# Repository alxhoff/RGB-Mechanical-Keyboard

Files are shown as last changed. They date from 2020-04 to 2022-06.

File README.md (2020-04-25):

# RGB-Mechanical-Keyboard

In this repository you will find my PCBs for a mechanical keyboard based around cherry switches and WS2812 single-wire serial RGB LEDs.
The keyboard is broken into two parts, the main keyboard PCB that houses the LEDS, power supply and switches, and a daughterboard that connects via ribbon cable where the controlling microcontroller is mounter.

The keyboard PCB in the latest generation has been been built such that the bottom row can be arranged in many different ways, allowing for unique configuration.
On the to-do list is to add this sort of customizability to more of the keyboard, eg. replacing capslock (totally useless) with a couple of macro keys.

# TODO for V2.1

- [x] Make second-from-bottom row more customizable
- [x] Add a usb 2.0 hub and a couple of usb-c ports to the keyboard.
- [X] Add jumpers to configure rgb rows, for example, daisy chaining multiple rows to reduce required pin count
- [ ] STM32F411 "Blackpill" control board
- [X] Add port for connecting a joystick for mouse functionality
- [X] Add switch for toggling 'BOOT' protocol, ie. device can recognize that it should send 8 byte BOOT compatible HID reports
- [X] Update existing control boards to handle 30 pin ribbon cable
- [X] Add hotswappable sockets
- [X] Make mounting holes elongated to allow for less precision during case fabrication

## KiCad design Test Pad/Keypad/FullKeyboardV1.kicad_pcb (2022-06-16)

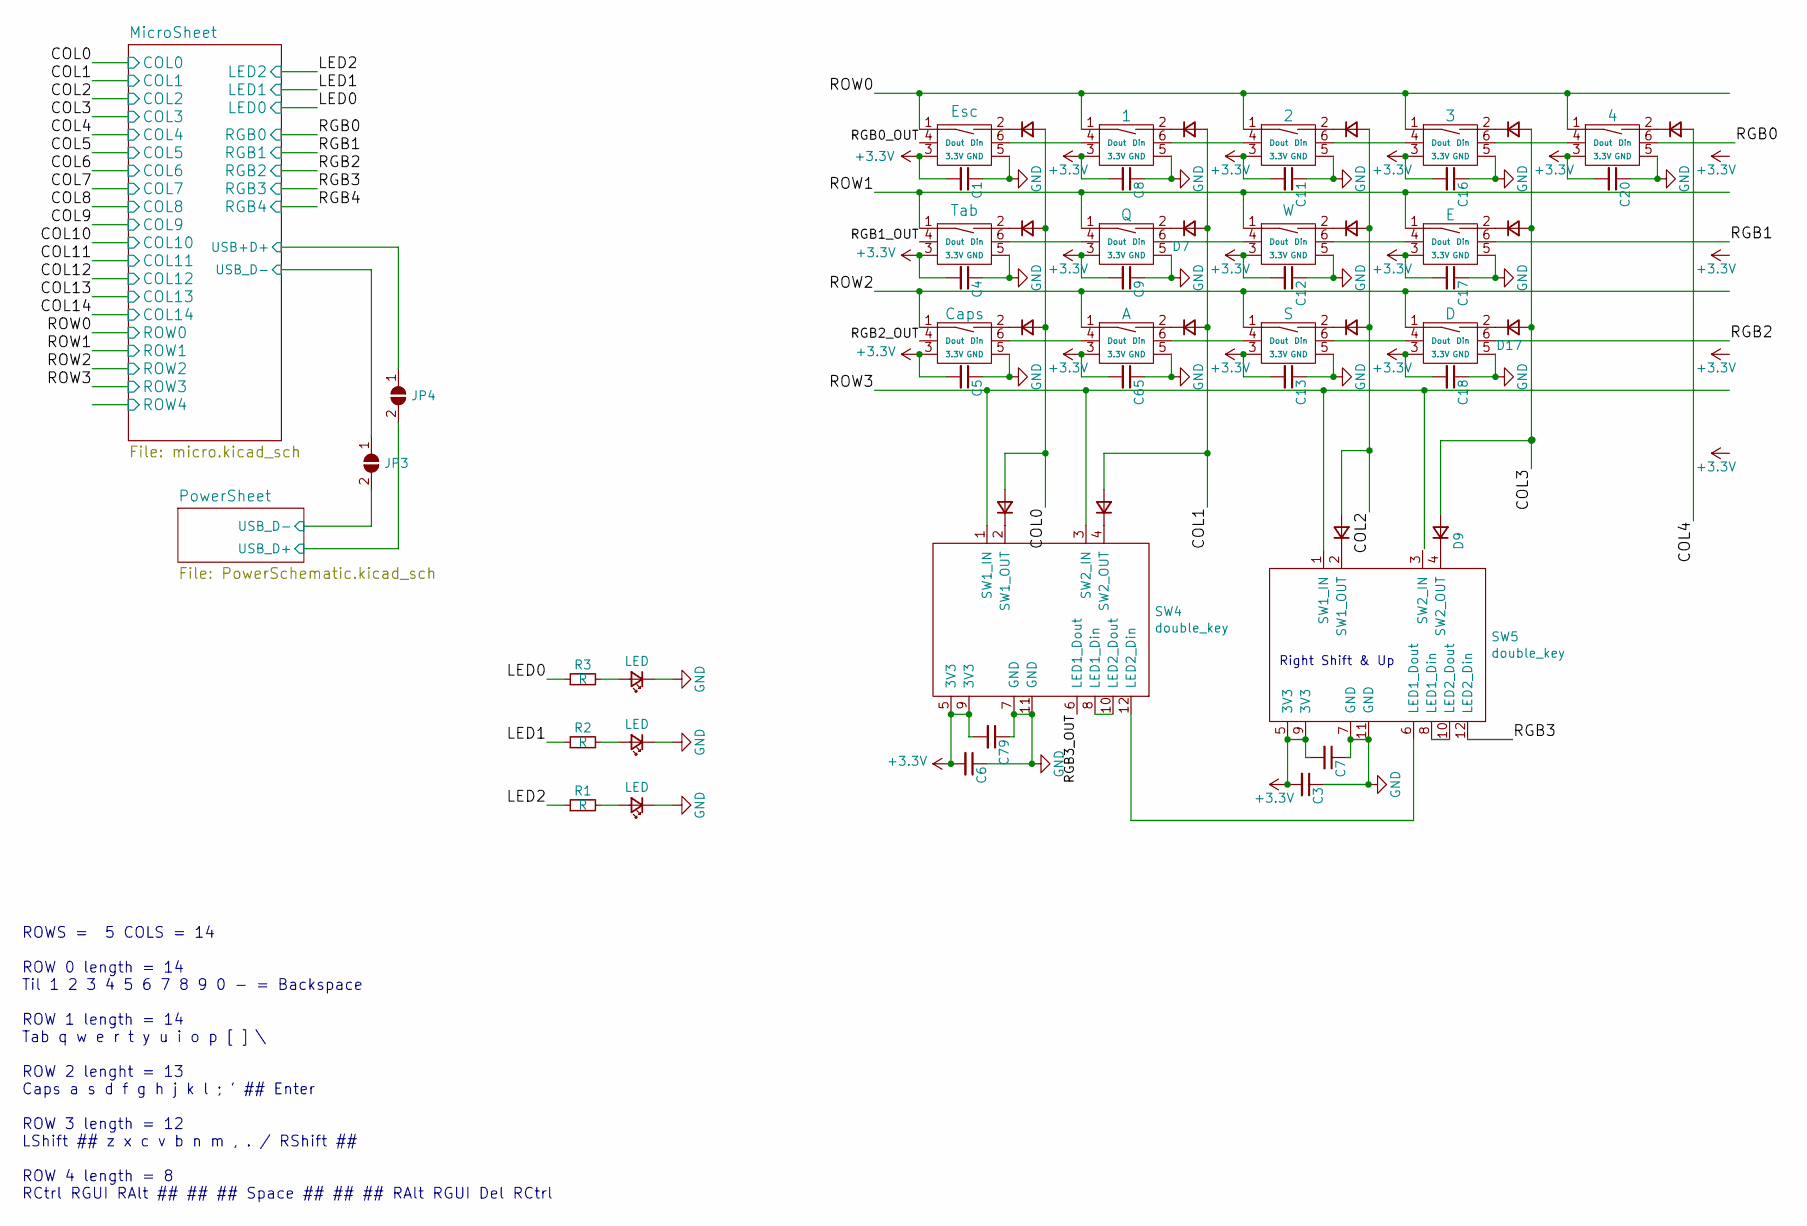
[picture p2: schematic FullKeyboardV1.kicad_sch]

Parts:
C1, C3, C4, C5, C6, C7, C8, C9, C11, C12, C13, C16, C17, C18, C20, C65, C79: C_Small; C_0603_1608Metric
D1, D2, D3, D4, D5, D6, D7, D8, D9, D10, D11, D12, D15, D16, D17, D19, D77: D_Small; D_SOD-123
D70, D71, D72: LED; LED_0603_1608Metric
JP3, JP4: SolderJumper_2_Open; SolderJumper-2_P1.3mm_Open_RoundedPad1.0x1.5mm
R1, R2, R3: R; R_0603_1608Metric
SW1: Esc; RGB_CHERRY_PCB_100H_HOTSWAP
SW2: Tab; RGB_CHERRY_PCB_150H_HOTSWAP
SW3: Caps; RGB_CHERRY_PCB_175H_HOTSWAP
SW4: double_key; RGB_CHERRY_SHIFT_ROW_LEFT
SW5: double_key; RGB_CHERRY_SHIFT_RIGHT_2.0
SW6: 1; RGB_CHERRY_PCB_100H_HOTSWAP
SW7: Q; RGB_CHERRY_PCB_100H_HOTSWAP
SW8: A; RGB_CHERRY_PCB_100H_HOTSWAP
SW10: 2; RGB_CHERRY_PCB_100H_HOTSWAP
SW11: W; RGB_CHERRY_PCB_100H_HOTSWAP
SW12: S; RGB_CHERRY_PCB_100H_HOTSWAP
SW15: 3; RGB_CHERRY_PCB_100H_HOTSWAP
SW16: E; RGB_CHERRY_PCB_100H_HOTSWAP
SW17: D; RGB_CHERRY_PCB_100H_HOTSWAP
SW19: 4; RGB_CHERRY_PCB_100H_HOTSWAP

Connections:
/COL0: D1.2 (A), D2.2 (A), D3.2 (A), D4.2 (A); also elsewhere on the board
/COL1: D6.2 (A), D7.2 (A), D8.2 (A), D77.2 (A); also elsewhere on the board
/COL2: D5.2 (A), D10.2 (A), D11.2 (A), D12.2 (A); also elsewhere on the board
/COL3: D9.2 (A), D15.2 (A), D16.2 (A), D17.2 (A); also elsewhere on the board
/COL4: D19.2 (A); also elsewhere on the board
/LED0: R3.1; also elsewhere on the board
/LED1: R2.1; also elsewhere on the board
/LED2: R1.1; also elsewhere on the board
/MicroSheet/USB+D+: JP4.1 (A); also elsewhere on the board
/MicroSheet/USB_D-: JP3.1 (A); also elsewhere on the board
/PowerSheet/USB_D+: JP4.2 (B); also elsewhere on the board
/PowerSheet/USB_D-: JP3.2 (B); also elsewhere on the board
/RGB0: SW19.6 (Din); also elsewhere on the board
/RGB0_OUT: SW1.4 (Dout)
/RGB1: SW16.6 (Din); also elsewhere on the board
/RGB1_OUT: SW2.4 (Dout)
/RGB2: SW17.6 (Din); also elsewhere on the board
/RGB2_OUT: SW3.4 (Dout)
/RGB3: SW5.12 (LED2_Din); also elsewhere on the board
/RGB3_OUT: SW4.6 (LED1_Dout)
/ROW0: SW1.1, SW6.1, SW10.1, SW15.1, SW19.1; also elsewhere on the board
/ROW1: SW2.1, SW7.1, SW11.1, SW16.1; also elsewhere on the board
/ROW2: SW3.1, SW8.1, SW12.1, SW17.1; also elsewhere on the board
/ROW3: SW4.1 (SW1_IN), SW4.3 (SW2_IN), SW5.1 (SW1_IN); also elsewhere on the board
GND: C1.1, C3.1, C4.1, C5.1, C6.1, C7.1, C8.1, C9.1, C11.1, C12.1, C13.1, C16.1, C17.1, C18.1, C20.1, C65.1, C79.1, D70.1 (K), D71.1 (K), D72.1 (K), SW1.5 (GND), SW2.5 (GND), SW3.5 (GND), SW4.7 (GND), SW4.11 (GND), SW5.7 (GND), SW5.11 (GND), SW6.5 (GND), SW7.5 (GND), SW8.5 (GND), SW10.5 (GND), SW11.5 (GND), SW12.5 (GND), SW15.5 (GND), SW16.5 (GND), SW17.5 (GND), SW19.5 (GND); also elsewhere on the board
unnamed: D1.1 (K), SW1.2
unnamed: D2.1 (K), SW2.2
unnamed: D3.1 (K), SW3.2
unnamed: D4.1 (K), SW4.2 (SW1_OUT)
unnamed: D5.1 (K), SW5.2 (SW1_OUT)
unnamed: D6.1 (K), SW6.2
unnamed: D7.1 (K), SW7.2
unnamed: D8.1 (K), SW8.2
unnamed: D9.1 (K), SW5.4 (SW2_OUT)
unnamed: D10.1 (K), SW10.2
unnamed: D11.1 (K), SW11.2
unnamed: D12.1 (K), SW12.2
unnamed: D15.1 (K), SW15.2
unnamed: D16.1 (K), SW16.2
unnamed: D17.1 (K), SW17.2
unnamed: D19.1 (K), SW19.2
unnamed: D70.2 (A), R1.2
unnamed: D71.2 (A), R2.2
unnamed: D72.2 (A), R3.2
unnamed: D77.1 (K), SW4.4 (SW2_OUT)
unnamed: SW1.6 (Din), SW6.4 (Dout)
unnamed: SW2.6 (Din), SW7.4 (Dout)
unnamed: SW3.6 (Din), SW8.4 (Dout)
unnamed: SW4.8 (LED1_Din), SW4.10 (LED2_Dout)
unnamed: SW4.12 (LED2_Din), SW5.6 (LED1_Dout)
unnamed: SW5.8 (LED1_Din), SW5.10 (LED2_Dout)
unnamed: SW6.6 (Din), SW10.4 (Dout)
unnamed: SW10.6 (Din), SW15.4 (Dout)
unnamed: SW7.6 (Din), SW11.4 (Dout)
unnamed: SW11.6 (Din), SW16.4 (Dout)
unnamed: SW8.6 (Din), SW12.4 (Dout)
unnamed: SW12.6 (Din), SW17.4 (Dout)
unnamed: SW15.6 (Din), SW19.4 (Dout)

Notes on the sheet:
Right Shift & Up
ROWS = 5 COLS = 14 ROW 0 length = 14 Til 1 2 3 4 5 6 7 8 9 0 - = Backspace ROW 1 length = 14 Tab q w e r t y u i o p [ ] \ ROW 2 lenght = 13 Caps a s d f g h j k l ; ' ## Enter ROW 3 length = 12 LShift ## z x c v b n m , . / RShift ## ROW 4 length = 8 RCtrl RGUI RAlt ## ## ## Space ## ## ## RAlt RG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

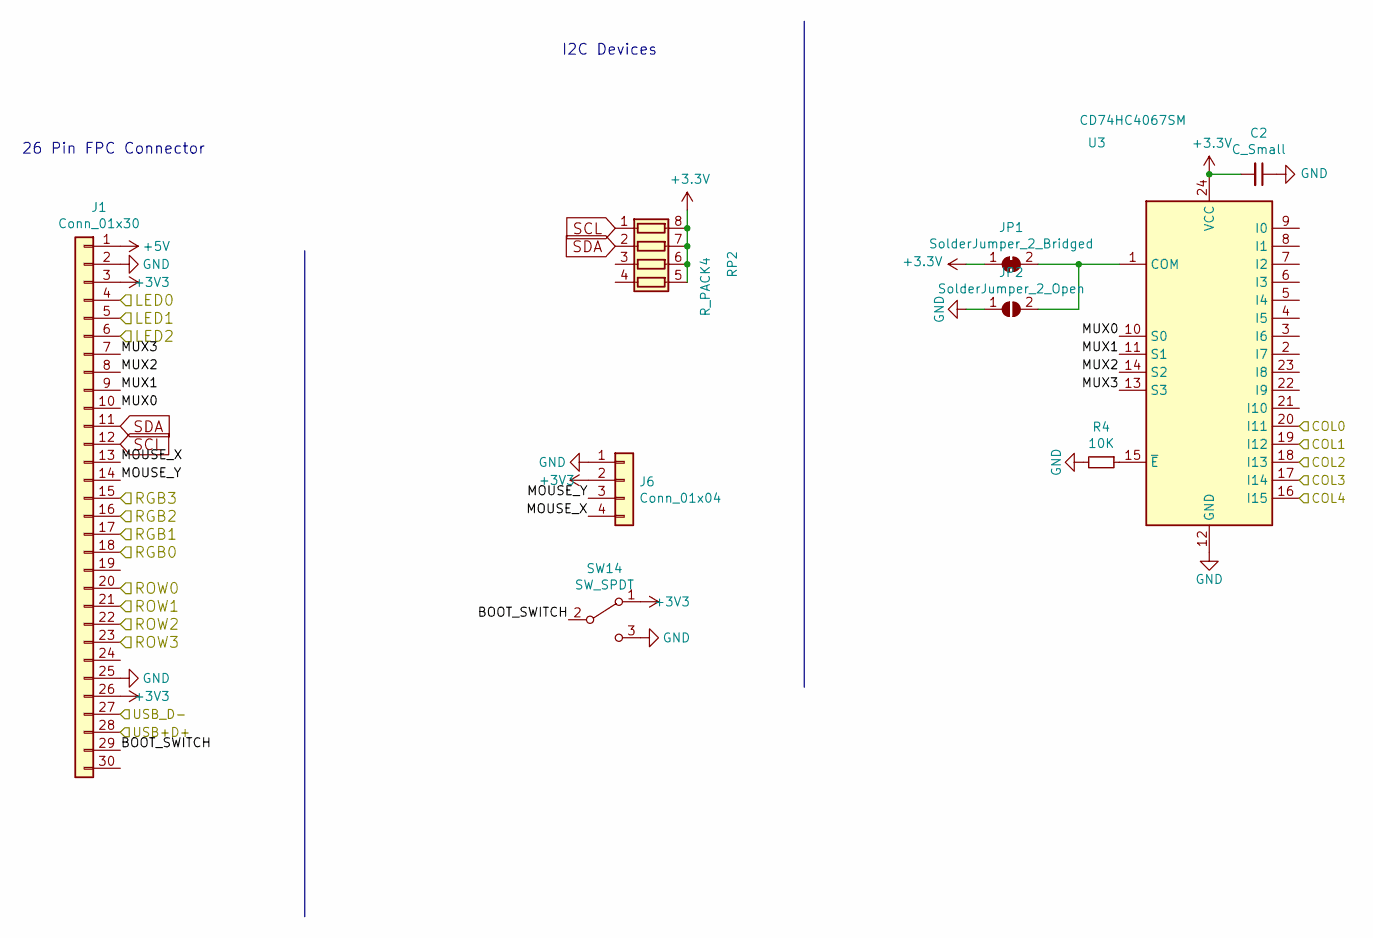
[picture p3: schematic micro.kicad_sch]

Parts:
C2: C_Small; C_0603_1608Metric
J1: Conn_01x30; Hirose_FH12-30S-0.5SH_1x30-1MP_P0.50mm_Horizontal
J6: Conn_01x04; JST_PH_S4B-PH-SM4-TB_1x04-1MP_P2.00mm_Horizontal
JP1: SolderJumper_2_Bridged; SolderJumper-2_P1.3mm_Bridged_RoundedPad1.0x1.5mm
JP2: SolderJumper_2_Open; SolderJumper-2_P1.3mm_Open_RoundedPad1.0x1.5mm
R4: 10K; R_0603_1608Metric
RP2: R_PACK4; R_Array_Concave_4x0402
SW14: SW_SPDT; SS12F23
U3: CD74HC4067SM; SSOP-24_5.3x8.2mm_P0.65mm

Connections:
+5V: J1.1; also elsewhere on the board
/COL0: U3.20 (I11); also elsewhere on the board
/COL1: U3.19 (I12); also elsewhere on the board
/COL2: U3.18 (I13); also elsewhere on the board
/COL3: U3.17 (I14); also elsewhere on the board
/COL4: U3.16 (I15); also elsewhere on the board
/LED0: J1.4; also elsewhere on the board
/LED1: J1.5; also elsewhere on the board
/LED2: J1.6; also elsewhere on the board
/MicroSheet/BOOT_SWITCH: J1.29, SW14.2 (B)
/MicroSheet/MOUSE_X: J1.13, J6.4
/MicroSheet/MOUSE_Y: J1.14, J6.3
/MicroSheet/MUX0: J1.10, U3.10 (S0)
/MicroSheet/MUX1: J1.9, U3.11 (S1)
/MicroSheet/MUX2: J1.8, U3.14 (S2)
/MicroSheet/MUX3: J1.7, U3.13 (S3)
/MicroSheet/USB+D+: J1.28; also elsewhere on the board
/MicroSheet/USB_D-: J1.27; also elsewhere on the board
/RGB0: J1.18; also elsewhere on the board
/RGB1: J1.17; also elsewhere on the board
/RGB2: J1.16; also elsewhere on the board
/RGB3: J1.15; also elsewhere on the board
/ROW0: J1.20; also elsewhere on the board
/ROW1: J1.21; also elsewhere on the board
/ROW2: J1.22; also elsewhere on the board
/ROW3: J1.23; also elsewhere on the board
GND: C2.1, J1.2, J1.25, J6.1, JP2.1 (A), R4.2, SW14.3 (C), U3.12 (GND); also elsewhere on the board
unnamed: JP1.2 (B), JP2.2 (B), U3.1 (COM)
unnamed: R4.1, U3.15 (~E)
SCL: J1.12, RP2.1 (R1.1)
SDA: J1.11, RP2.2 (R2.1)

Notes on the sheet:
I2C Devices
26 Pin FPC Connector

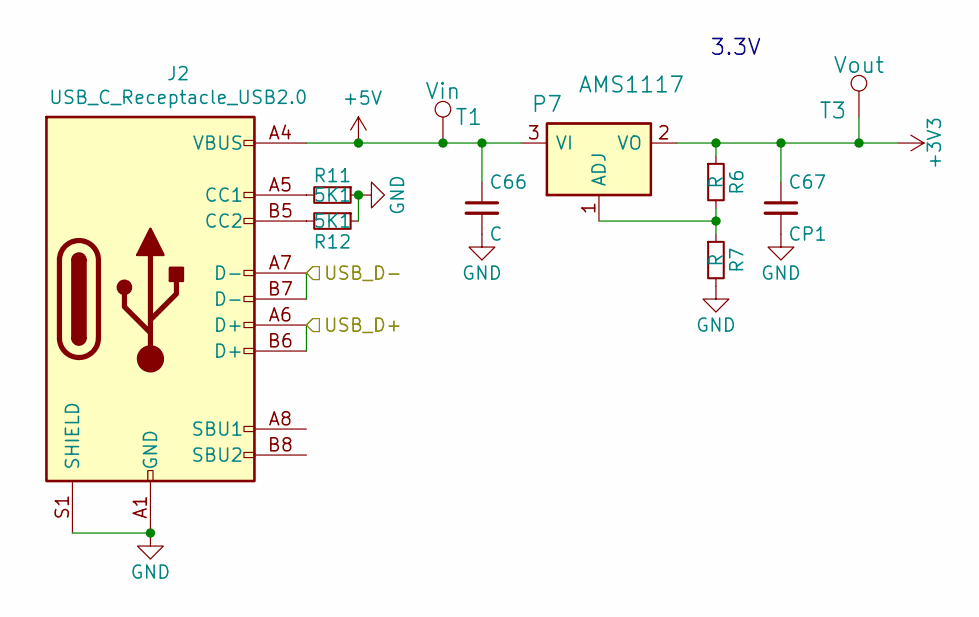
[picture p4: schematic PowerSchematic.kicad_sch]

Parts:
C66: C; C_0603_1608Metric
C67: CP1; C_0603_1608Metric
J2: USB_C_Receptacle_USB2.0; USB_C_Receptacle_HRO_TYPE-C-31-M-12
P7: AMS1117; SOT-223
R6, R7: R; R_0603_1608Metric
R11, R12: 5K1; R_0603_1608Metric
T1: Vin; TestPoint_Pad_1.0x1.0mm
T3: Vout; TestPoint_Pad_1.0x1.0mm

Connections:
+5V: C66.1, J2.A4 (VBUS), J2.A9 (VBUS), J2.B4 (VBUS), J2.B9 (VBUS), P7.3 (VI), T1.1; also elsewhere on the board
/PowerSheet/USB_D+: J2.A6 (D+), J2.B6 (D+); also elsewhere on the board
/PowerSheet/USB_D-: J2.A7 (D-), J2.B7 (D-); also elsewhere on the board
GND: C66.2, C67.2, J2.A1 (GND), J2.A12 (GND), J2.B1 (GND), J2.B12 (GND), J2.S1 (SHIELD), R7.2, R11.1, R12.1; also elsewhere on the board
unnamed: J2.A5 (CC1), R11.2
unnamed: J2.B5 (CC2), R12.2
unnamed: P7.1 (ADJ), R6.2, R7.1

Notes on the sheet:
3.3V

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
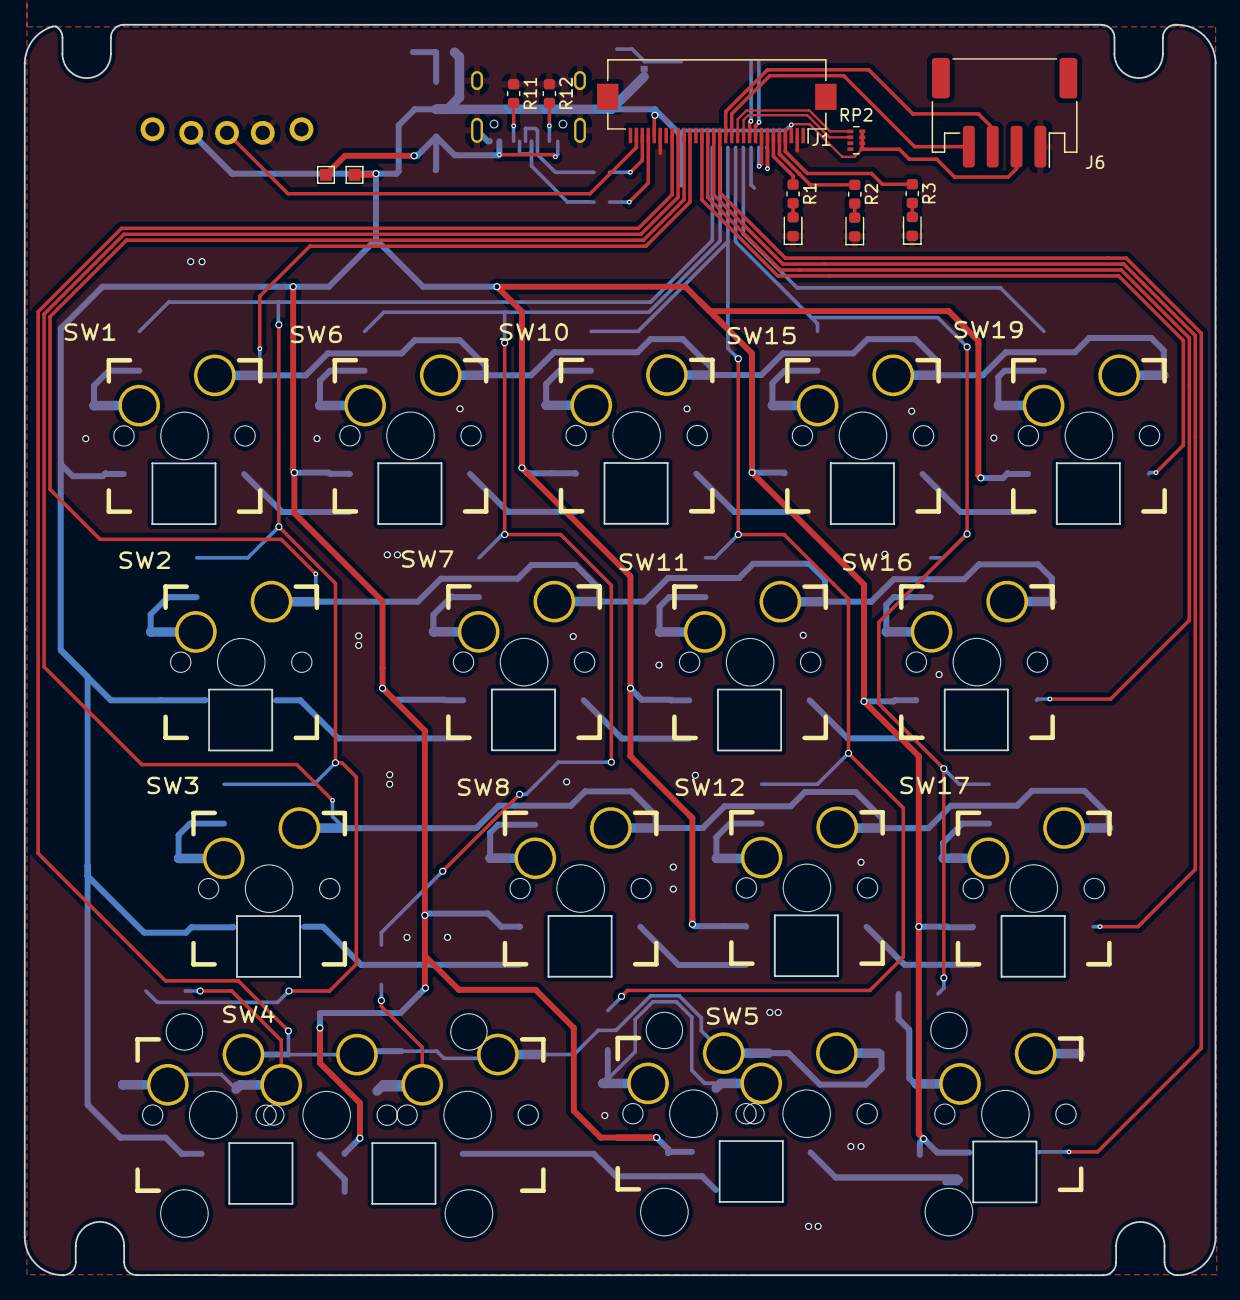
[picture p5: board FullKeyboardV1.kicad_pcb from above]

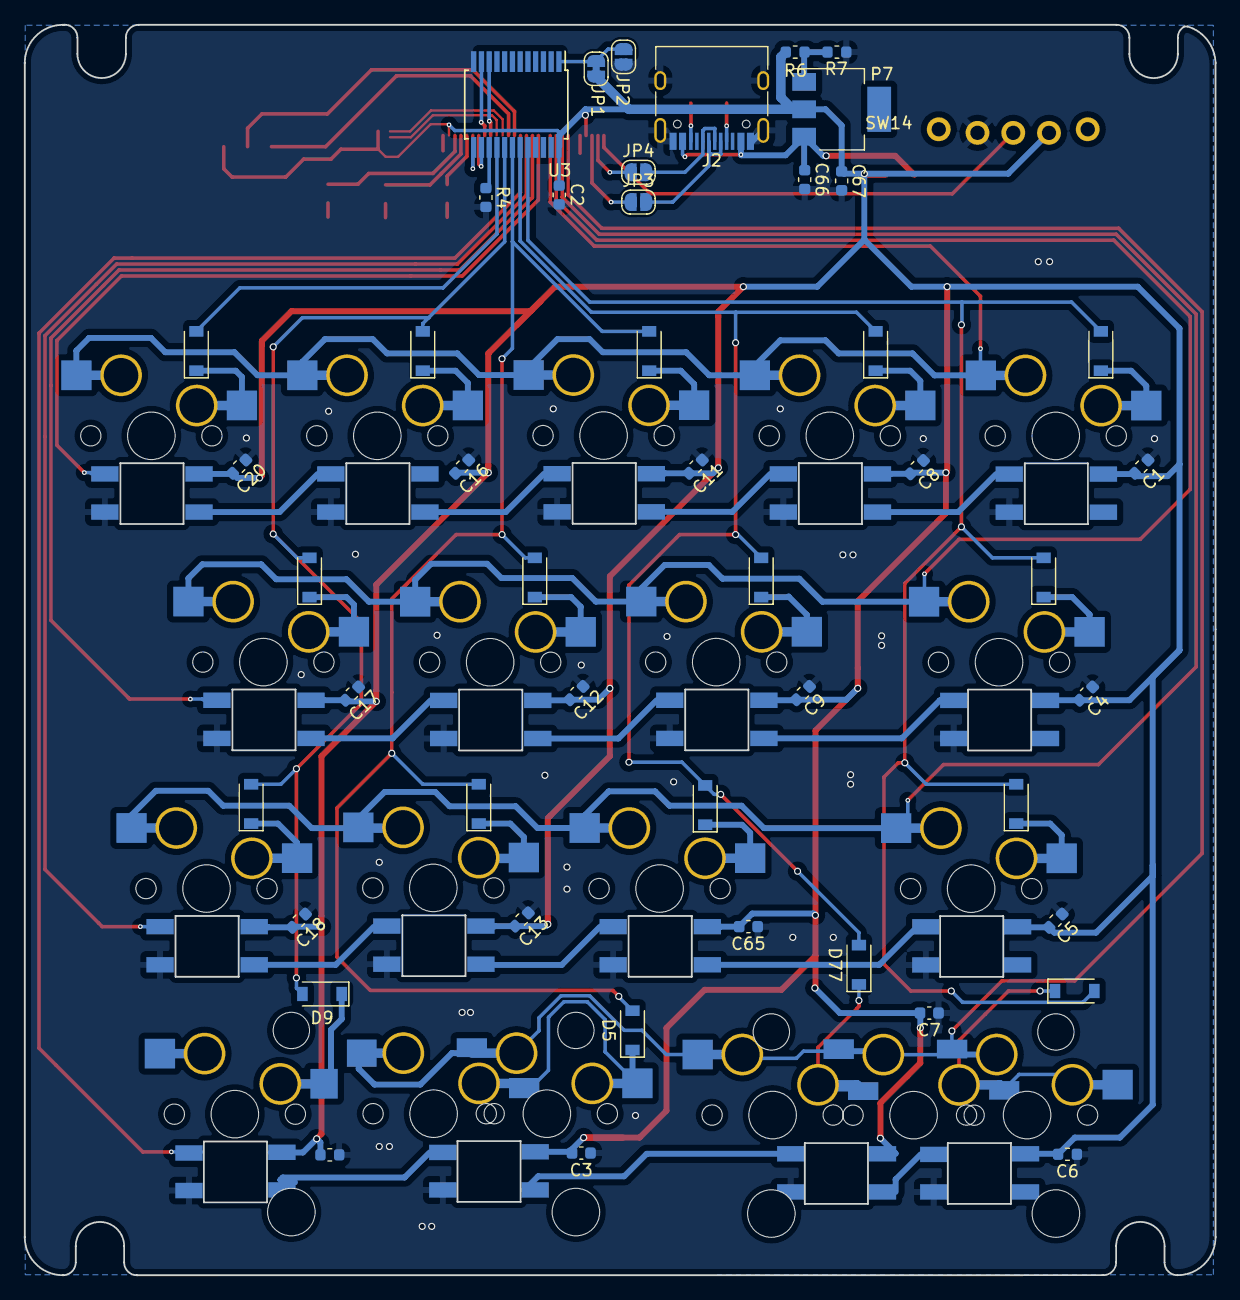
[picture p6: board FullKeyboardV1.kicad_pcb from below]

Board: 2 copper layers, 99.9 x 104.9 mm, 76 parts (48 on the bottom side), 70 nets.

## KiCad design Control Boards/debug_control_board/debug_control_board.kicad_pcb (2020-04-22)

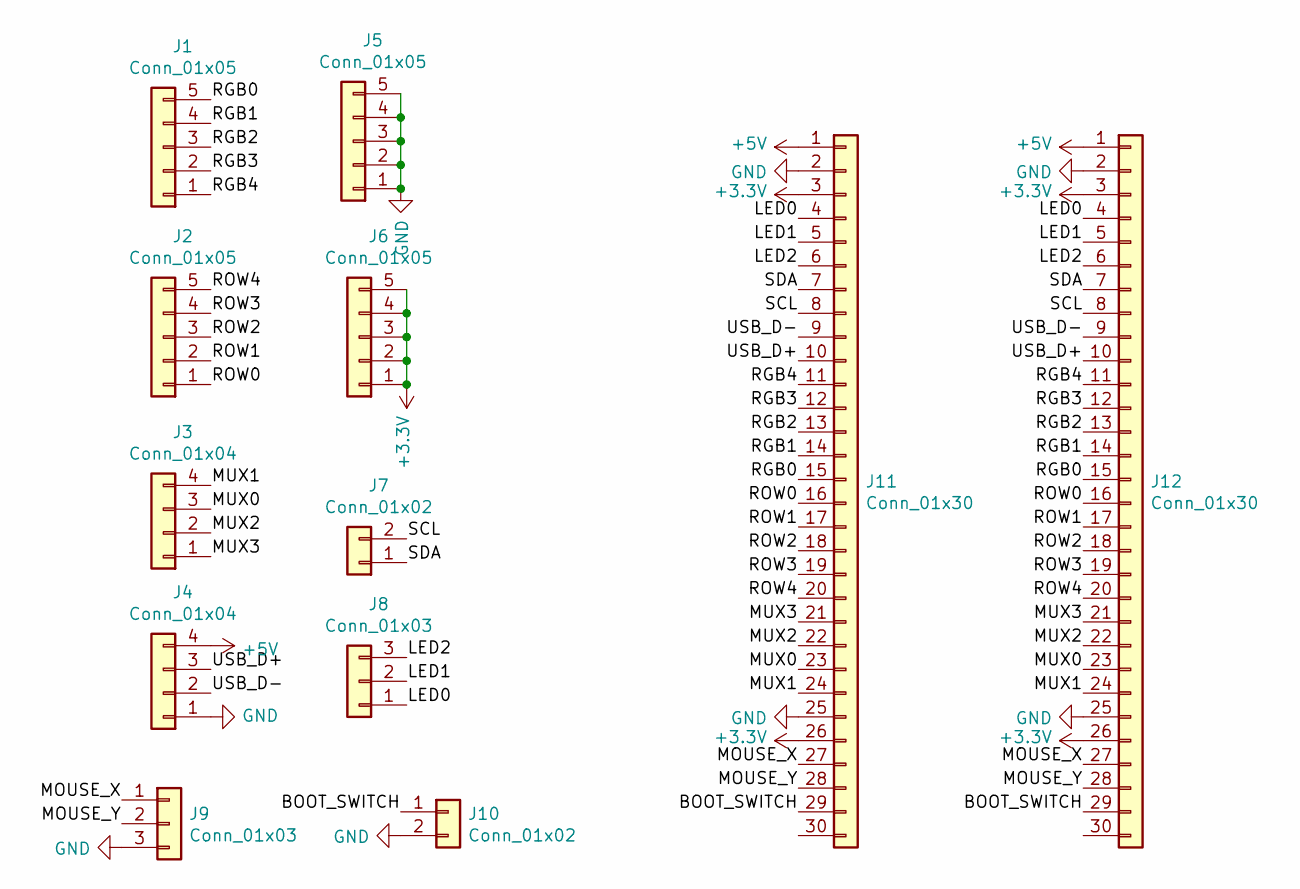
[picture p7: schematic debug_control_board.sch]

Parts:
J1, J2, J5, J6: Conn_01x05; PinHeader_1x05_P2.54mm_Vertical
J3, J4: Conn_01x04; PinHeader_1x04_P2.54mm_Vertical
J7, J10: Conn_01x02; PinHeader_1x02_P2.54mm_Vertical
J8, J9: Conn_01x03; PinHeader_1x03_P2.54mm_Vertical
J11, J12: Conn_01x30; Hirose_FH12-30S-0.5SH_1x30-1MP_P0.50mm_Horizontal

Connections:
+3V3: J6.1, J6.2, J6.3, J6.4, J6.5, J11.3, J11.26, J12.3, J12.26
+5V: J4.4, J11.1, J12.1
/BOOT_SWITCH: J10.1, J11.29, J12.29
/LED0: J8.1, J11.4, J12.4
/LED1: J8.2, J11.5, J12.5
/LED2: J8.3, J11.6, J12.6
/MOUSE_X: J9.1, J11.27, J12.27
/MOUSE_Y: J9.2, J11.28, J12.28
/MUX0: J3.3, J11.23, J12.23
/MUX1: J3.4, J11.24, J12.24
/MUX2: J3.2, J11.22, J12.22
/MUX3: J3.1, J11.21, J12.21
/RGB0: J1.5, J11.15, J12.15
/RGB1: J1.4, J11.14, J12.14
/RGB2: J1.3, J11.13, J12.13
/RGB3: J1.2, J11.12, J12.12
/RGB4: J1.1, J11.11, J12.11
/ROW0: J2.1, J11.16, J12.16
/ROW1: J2.2, J11.17, J12.17
/ROW2: J2.3, J11.18, J12.18
/ROW3: J2.4, J11.19, J12.19
/ROW4: J2.5, J11.20, J12.20
/SCL: J7.2, J11.8, J12.8
/SDA: J7.1, J11.7, J12.7
/USB_D+: J4.3, J11.10, J12.10
/USB_D-: J4.2, J11.9, J12.9
GND: J4.1, J5.1, J5.2, J5.3, J5.4, J5.5, J9.3, J10.2, J11.2, J11.25, J12.2, J12.25

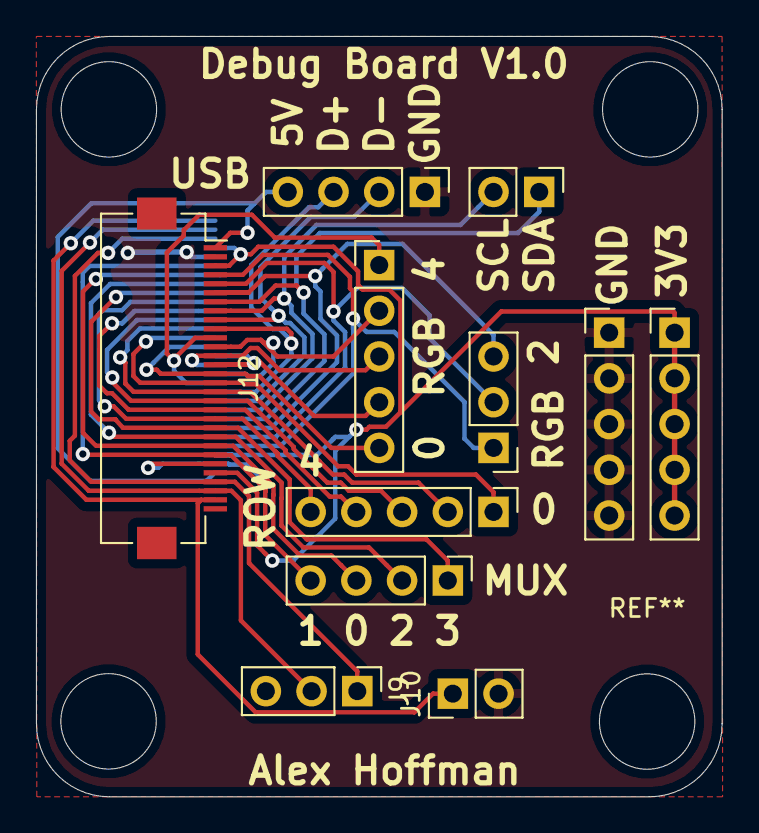
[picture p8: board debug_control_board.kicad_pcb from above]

Board: 2 copper layers, 38.1 x 42.2 mm, 12 parts (1 on the bottom side), 27 nets.

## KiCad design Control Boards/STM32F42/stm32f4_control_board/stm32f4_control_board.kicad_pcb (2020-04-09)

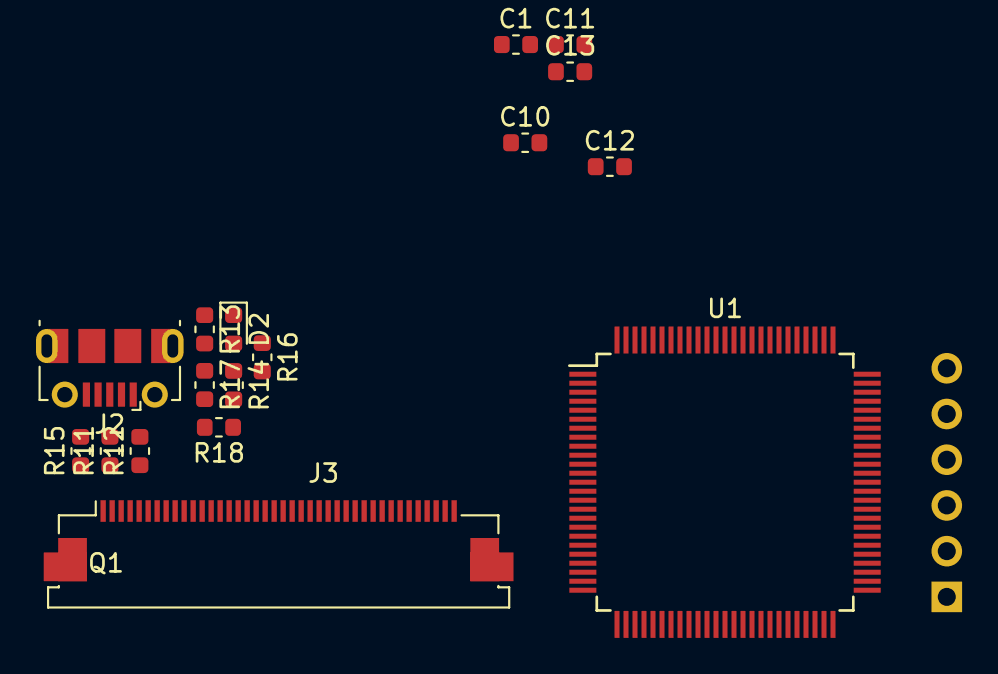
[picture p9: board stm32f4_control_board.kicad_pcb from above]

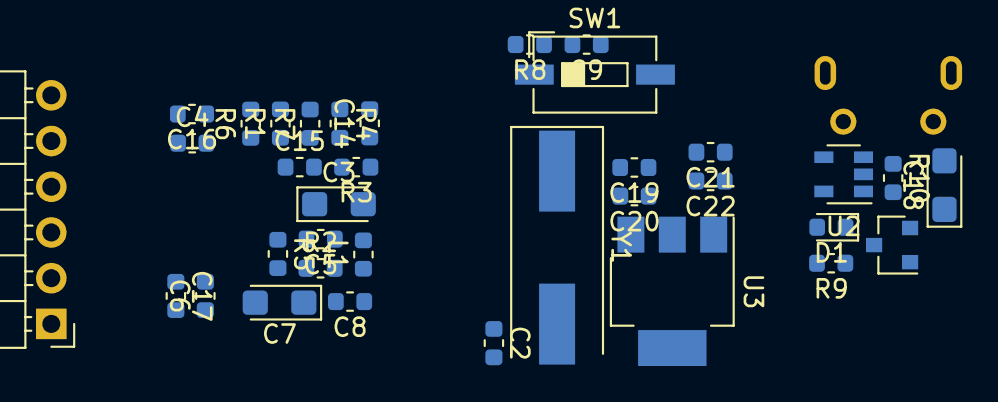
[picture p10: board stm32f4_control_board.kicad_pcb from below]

Board: 2 copper layers, 52 parts (35 on the bottom side), 54 nets, no tracks yet.

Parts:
C1, C2: 20pF; C_0603_1608Metric
C3, C7, C18: 1uF; CP_EIA-3216-18_Kemet-A
C4, C6: 2.2uF; C_0603_1608Metric
C5, C8, C9, C10, C11, C12, C13, C14, C15, C16, C17, C20, C22: 100nF; C_0603_1608Metric
C19, C21: 1uF; C_0603_1608Metric
D1: Green; D_0603_1608Metric
D2: Red; D_0603_1608Metric
J1: Conn_01x06_Female; PinHeader_1x06_P2.54mm_Horizontal
J2: USB_B_Micro; USB_Micro-B_Molex-105017-0001
J3: Conn_01x26_Female; Molex_54132-5033_1x40-1MP_P0.5mm_Horizontal
L1: L_Small; L_0603_1608Metric
Q1: 9013; SOT-23
R1: 510; R_0603_1608Metric
R2: 47; R_0603_1608Metric
R3, R4, R15, R17: 0; R_0603_1608Metric
R5, R8, R18: 10K; R_0603_1608Metric
R6, R7: 4K7; R_0603_1608Metric
R9: 330; R_0603_1608Metric
R10, R13, R14, R16: 47K; R_0603_1608Metric
R11, R12: 22; R_0603_1608Metric
SW1: SW_Push; SW_DIP_SPSTx01_Slide_6.7x4.1mm_W6.73mm_P2.54mm_LowProfile_J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
U1: STM32F407VGTx; LQFP-100_14x14mm_P0.5mm
U2: STMPS2141; SOT-23-5
U3: AMS1117-3.3; SOT-223-3_TabPin2
Y1: 8MHz; Crystal_SMD_HC49-SD

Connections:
+3V3: C21.2, C22.2, J3.26, R9.1, R14.2, R16.2, R18.1, U3.2
+5V: C19.2, C20.2, J3.1, J3.25, U2.5, U3.3
GPIO2: J3.3, U1.16
GPIO3: J3.4, U1.17
GPIO4: J3.5, U1.18
GPIO5: J3.6, U1.1
GPIO6: J3.7, U1.2
GPIO7: J3.8, U1.3
GPIO8: J3.9, U1.4
GPIO9: J3.10, U1.5
GPIO10: J3.11, U1.23
GPIO11: J3.12, U1.24
GPIO12: J3.13, U1.29
I2C3_SCL: J3.18, U1.67
I2C3_SDA: J3.17, U1.66
MCO: C1.2, J1.1, U1.12, Y1.1
NRST: C9.2, J1.3, R8.1, SW1.1, U1.14
unnamed: C2.2, U1.13, Y1.2
unnamed: C4.1, U1.73
unnamed: C6.1, U1.49
unnamed: D1.1, Q1.3
unnamed: D1.2, R9.2
unnamed: D2.1, R13.2, R16.1, U2.3
unnamed: D2.2, R14.1
unnamed: J2.2, R12.2
unnamed: J2.3, R11.2
unnamed: J2.4, R15.2
unnamed: Q1.2, R10.2
unnamed: R1.2, U1.94
unnamed: R2.2, U1.21
unnamed: R3.1, U1.6
unnamed: R4.1, U1.99
unnamed: R5.2, U1.37
unnamed: R17.1, U2.4
OTF_GS_overcurrent: R13.1, U1.86
PB6-I2C1_SCL: J3.22, U1.92
PB9-I2C1_SDA: J3.23, U1.96
PC0: R17.2, R18.2, U1.15
SPI_MISO: J3.20, U1.31
SPI_MOSI: J3.19, U1.32
SPI_SCK: J3.21, U1.30
SWCLK: J1.5, U1.76
SWDIO: J1.4, U1.72
SWO: J1.6, U1.89
UART2_CK: J3.16, U1.88
UART2_RX: J3.15, U1.26
UART2_TX: J3.14, U1.25
USB_OTG_DM: R12.1, U1.70
USB_OTG_DP: R11.1, U1.71
USB_OTG_GND: C1.1, C2.1, C3.2, C4.2, C5.1, C6.2, C7.2, C8.1, C9.1, C10.1, C11.1, C12.1, C13.1, C14.1, C15.1, C16.1, C17.1, C18.2, C19.1, C20.1, C21.1, C22.1, J1.2, J2.5, J2.6, J3.2, J3.24, Q1.1, R1.1, R4.2, SW1.2, U1.10, U1.20, U1.27, U1.74, U2.2, U3.1
USB_OTG_ID: R15.1, U1.69
USB_OTG_VBUS: C18.1, J2.1, R10.1, U1.68, U2.1
VDD: C10.2, C11.2, C12.2, C13.2, C14.2, C15.2, C16.2, C17.2, L1.2, R3.2, R5.1, R6.1, R7.1, R8.2, U1.11, U1.19, U1.28, U1.50, U1.75, U1.100
VDDA: C3.1, C5.2, C7.1, C8.2, L1.1, R2.1, U1.22

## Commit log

2020-04-13 Added USB HUB
    [FullKeyboardV1.kicad_pcb, FullKeyboardV1.sch, PowerSchematic.sch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]
2020-04-14 Added multi-function left and right shift
    [FullKeyboardV1.kicad_pcb, FullKeyboardV1.sch]
2020-04-22 Added solder jumpers to allow for daisy chaining RGB rows
    [FullKeyboardV1.kicad_pcb, FullKeyboardV1.sch, PowerSchematic.sch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]
2020-04-22 Updated footprints on keyboard PCB
    [FullKeyboardV1.kicad_pcb]
2020-04-22 Updated bluepill board for 30pin ribbon cable
    [FullKeyboardV1.kicad_pcb, bluepill_control_board.kicad_pcb, bluepill_control_board.sch]
2020-04-22 Added BOOT switch
    [FullKeyboardV1.kicad_pcb, bluepill_control_board.kicad_pcb, bluepill_control_board.sch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]
2020-04-22 Updated debug board to support 30 pin ribbon cable
    [debug_control_board.kicad_pcb, debug_control_board.sch]
2020-04-24 added hotswap sockets
    [FullKeyboardV1.kicad_pcb]
2020-04-25 Modified mounting holes
    [FullKeyboardV1.kicad_pcb]
2022-06-13 Started test pad
    [FullKeyboardV1-2020-04-07-00-28-51.sch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]
2022-06-16 Started nucleo 144 test pad and keypad boards
    [FullKeyboardV1-2020-04-07-00-28-51.sch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]
